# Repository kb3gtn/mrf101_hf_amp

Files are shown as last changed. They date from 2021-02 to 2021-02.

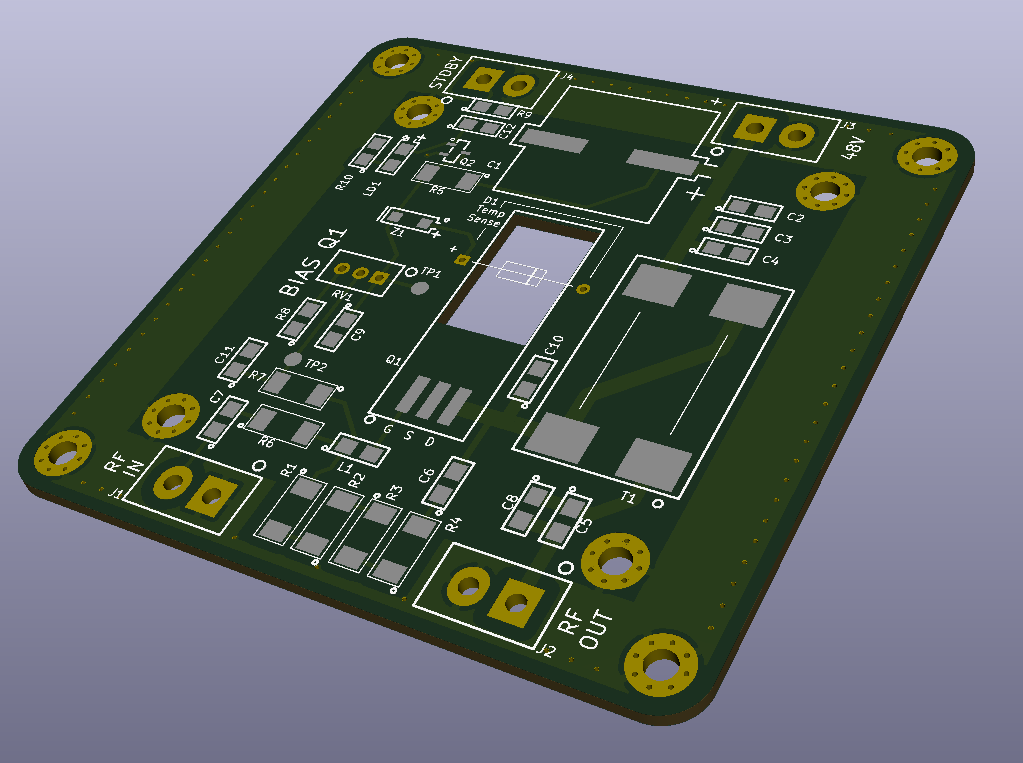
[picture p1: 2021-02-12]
Amp_Main_Deck/kicad/PCB_3D_Render.png

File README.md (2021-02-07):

# MRF101 HF AMP design

## Introduction
This repository contains multiple circuits board designs for a 100W HF Amp using a single MRF-101A transistor.   This design is based on a design by HF5L.   This design operates with a 48V Nominal supply at around 3.5 Amps of current.

Input match is good from 160M -> 6M band (1.8M -> 54 MHz).   Device has a between 16 -> 20 dB of gain depending on frequency.

## KICAD design files
The Main Amp Deck consists of the MRF101 transistor and input/output matching circuitry.
This can be found in the /Amp_Main_Deck/kicad folder in this repository.   The amplifier deck requires output filtering to remove odd harmonics produced by the Class AB amp.   The filters are selected per band of operation.

## Powering the Amp
The concept to power the amplifier design is to use 2 6S LiPo batteries in series.  This will provide a 44 -> 52v operating range.  Current plan is to use RC batteries and off the shelf chargers for portable operation.

## TODO
Design some BFP filters for each of the HF Amateur Radio bands, will need to develop a switch bank to select which filter should be in line.   Using BPF because this will provide some selectivity and limit the amount of bandwidth being sampled for a SDR receiver architecture.

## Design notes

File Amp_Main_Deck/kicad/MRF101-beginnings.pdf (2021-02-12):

## MRF-101 HF Amp 1.8-54 MHz

Peter Fetterer [ KB3GTN ]

Purpose of this project is to evaluate and generally dork around with some LDMOS MOSFET Amplifiers as a learning exercise. Looking around at possible devices I came across the MRF-101A transistor.

After a little googling I found a NXP Homebrew entry from Jim Veatch (WA2EUJ) where he made this device work as a broadband 100W Amp. So, to start of I decided to start with his design, build it, and see what it is capable of.

This is some documentation of some beginning test and evaluations of this Amplifier design.

The design files for this Amp are available on my Github located at the following URL: https://github.com/kb3gtn/mrf101_hf_amp

Schematic is available as a PDF in the repository.

3D render of the PCB created:


PCB dimensions:

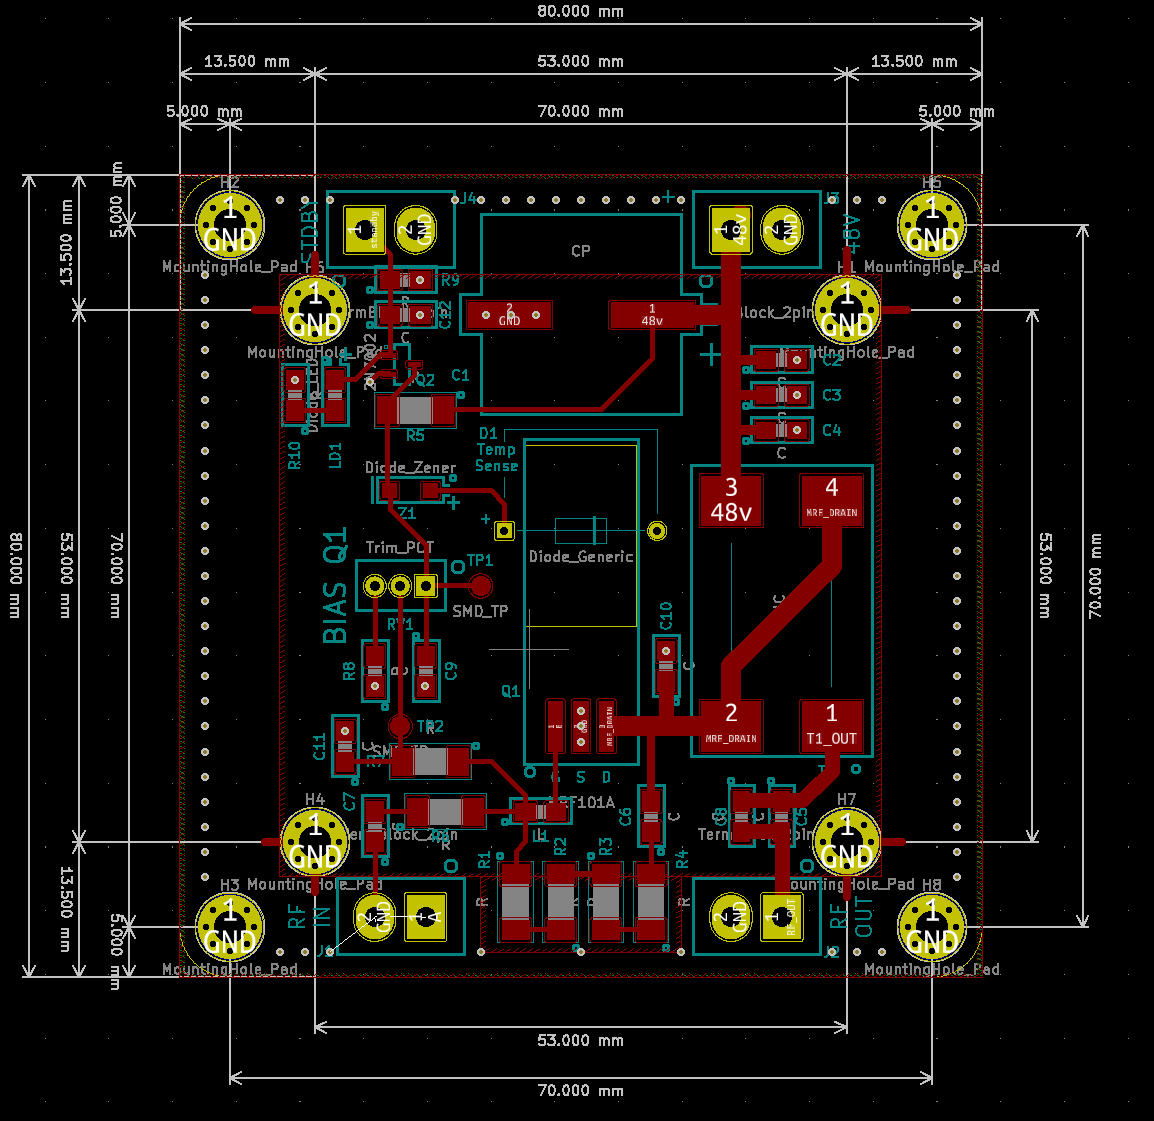
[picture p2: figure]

Heatsink mounts to inner hole pattern. Transistor mounts directly to heatsink.

The workbench for this project:

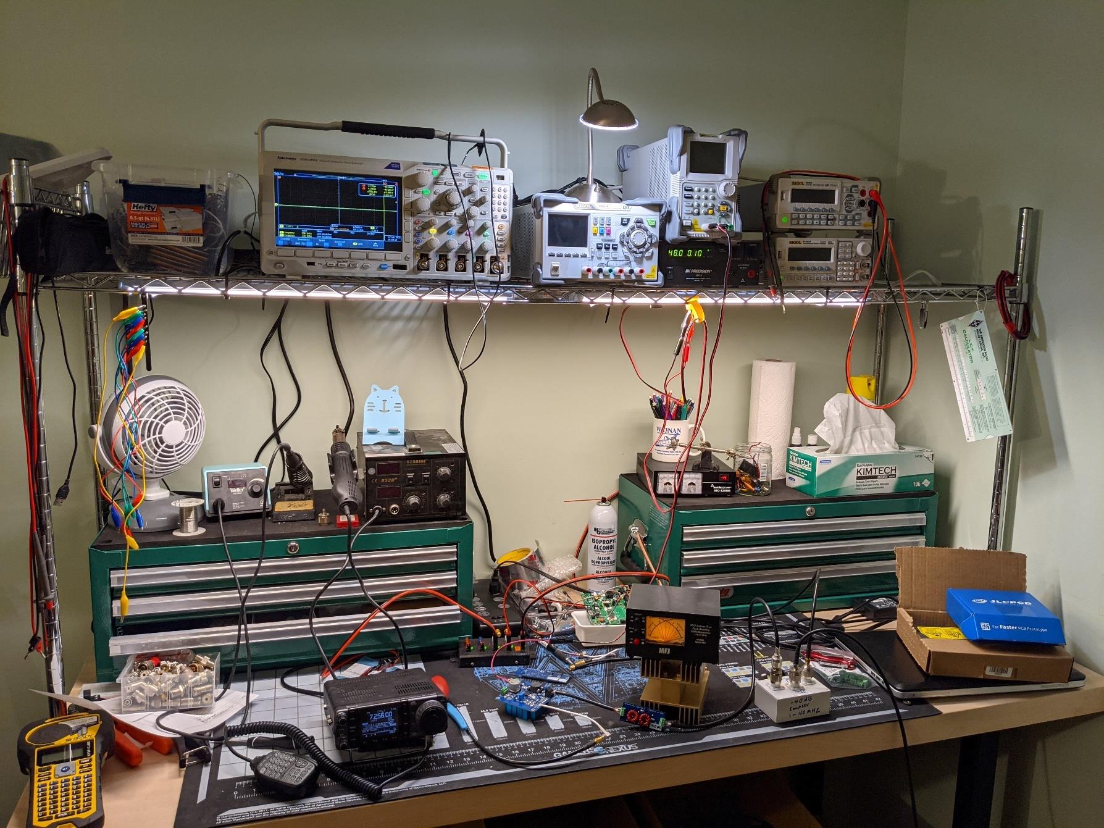
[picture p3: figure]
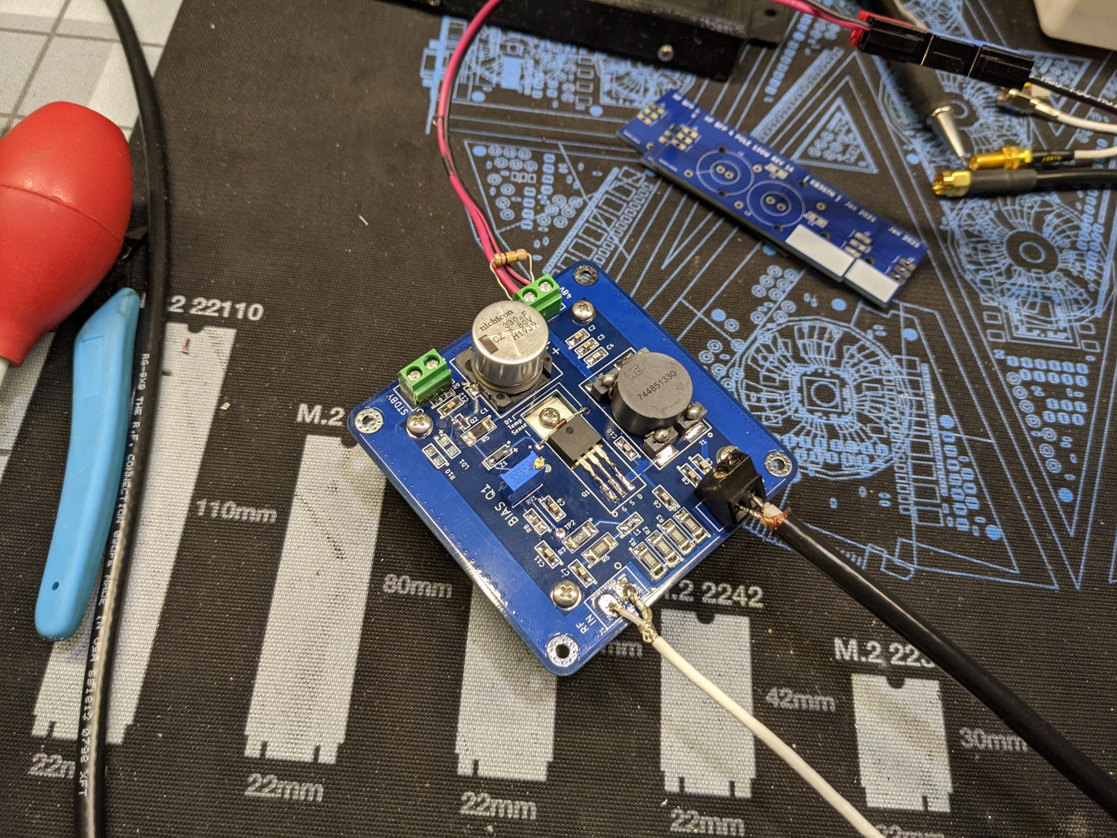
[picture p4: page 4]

HF Amplifier Deck close look.

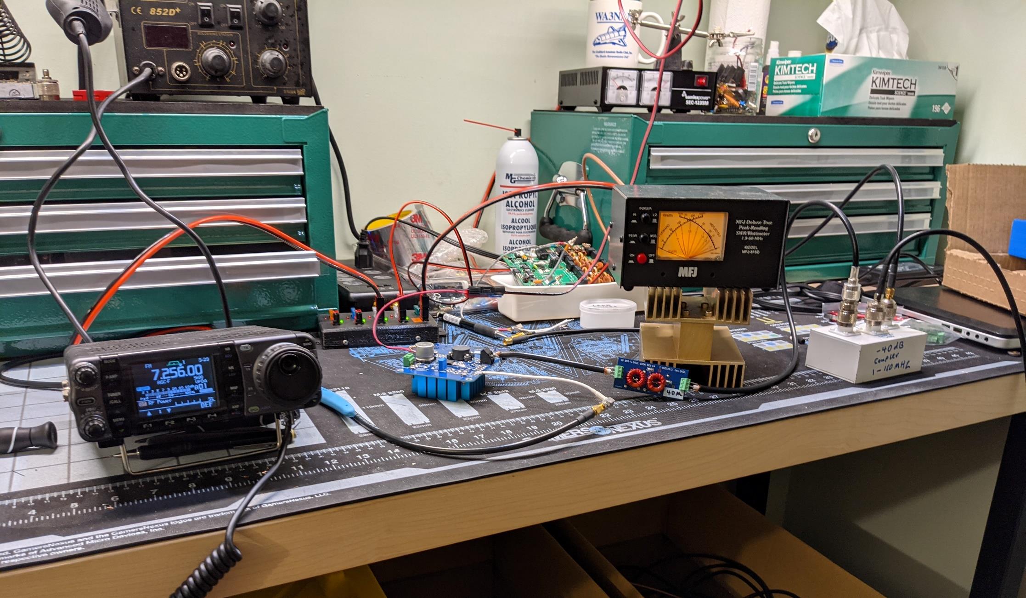
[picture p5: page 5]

Shows Amplifier Deck and Heatsink and a 40M BPF in test Configuration.

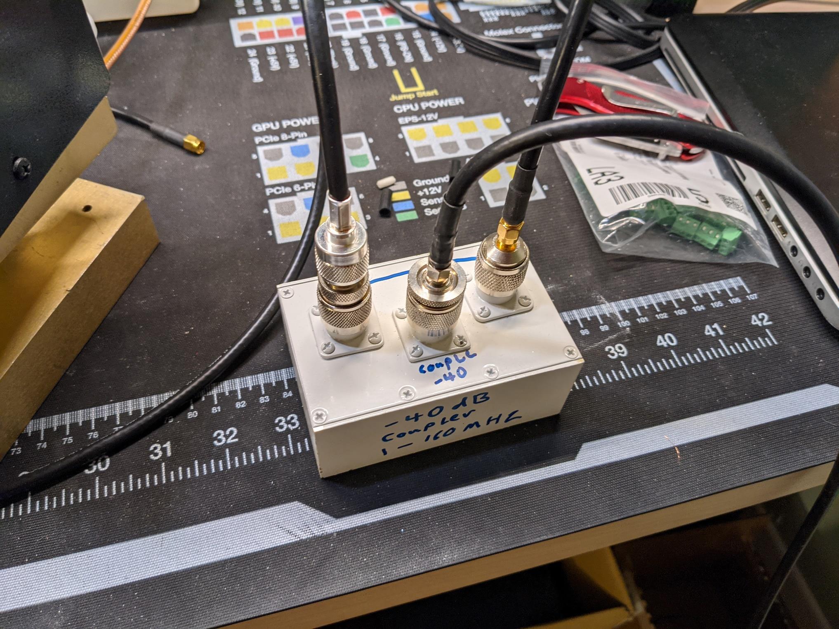
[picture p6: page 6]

Homebrew -40 dB coupler for looking at High Power signal on Spectrum Analyzer.

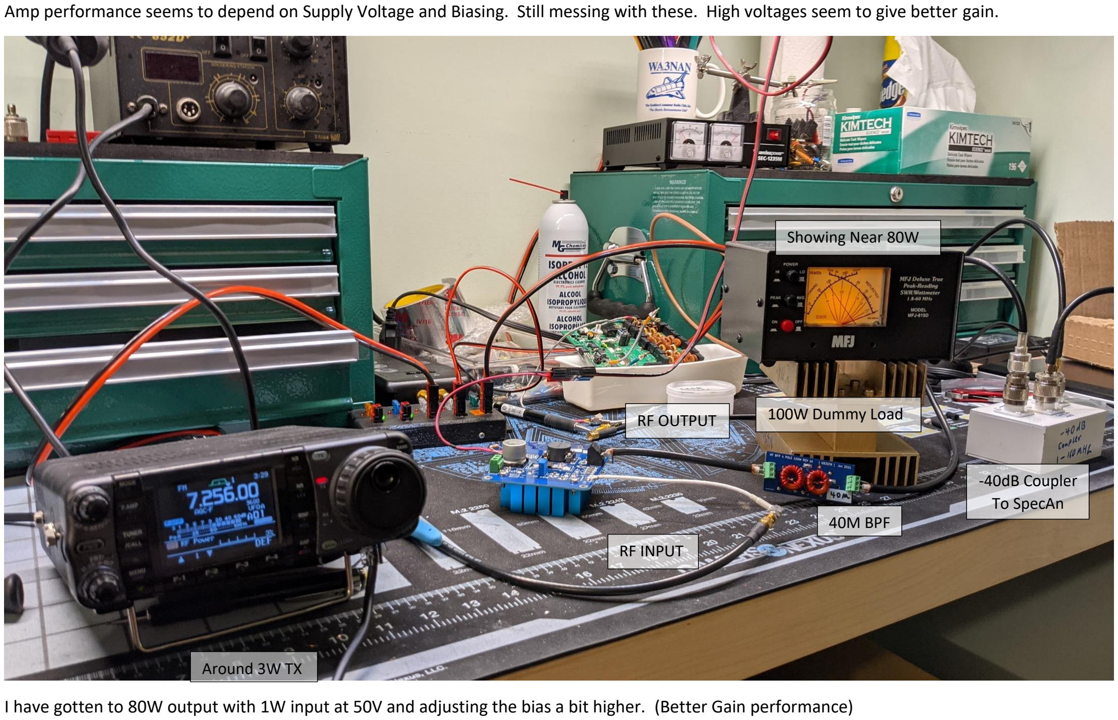
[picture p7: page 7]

Amp performance seems to depend on Supply Voltage and Biasing. Still messing with these. High voltages seem to give better gain.

I have gotten to 80W output with 1W input at 50V and adjusting the bias a bit higher. (Better Gain performance)

Around 3W TX

RF INPUT

RF OUTPUT

40M BPF

-40dB Coupler
To SpecAn

Showing Near 80W

100W Dummy Load

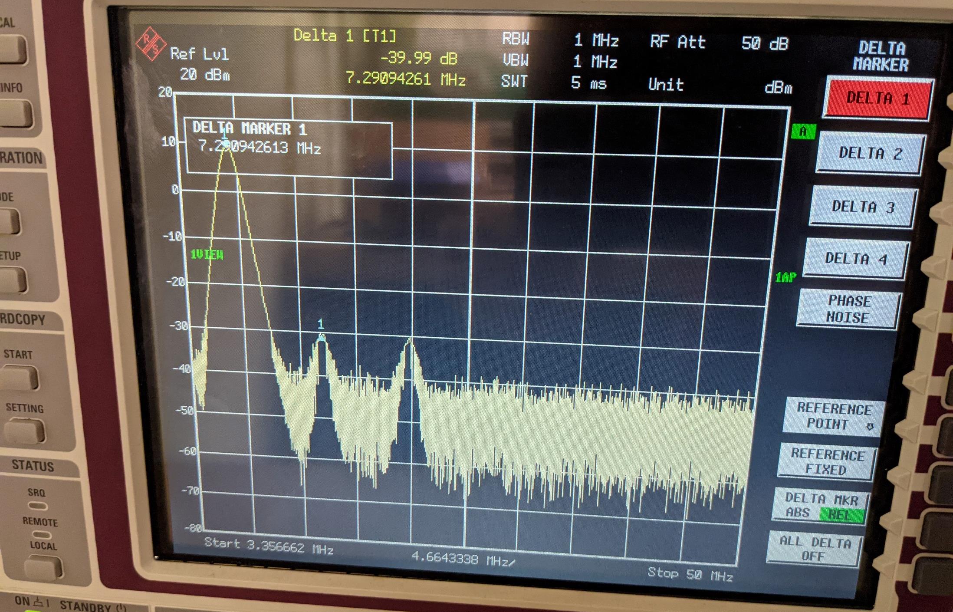
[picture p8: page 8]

Band Pass Filter Harmonic Suppression. Appears this configuration is providing about -40 dBc attenuation to 2nd and 3rd harmonics for 40M.

Conclusion:

Initial dorking around with the design seems to suggest it will do ok for project I want to use this for going forward. May rework this board to be Pre-Driver, MRF101 Amp, and Filter bank on a single board going for a small compact footprint that can run off an external 2 6S LiPo RC battery packs in series.

More to come, maybe..

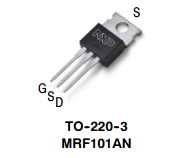
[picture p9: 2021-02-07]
Amp_Main_Deck/kicad/mrf101_pinout.png

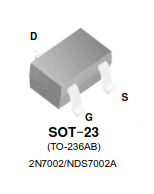
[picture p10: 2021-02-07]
Amp_Main_Deck/kicad/2n7002_pinout.png

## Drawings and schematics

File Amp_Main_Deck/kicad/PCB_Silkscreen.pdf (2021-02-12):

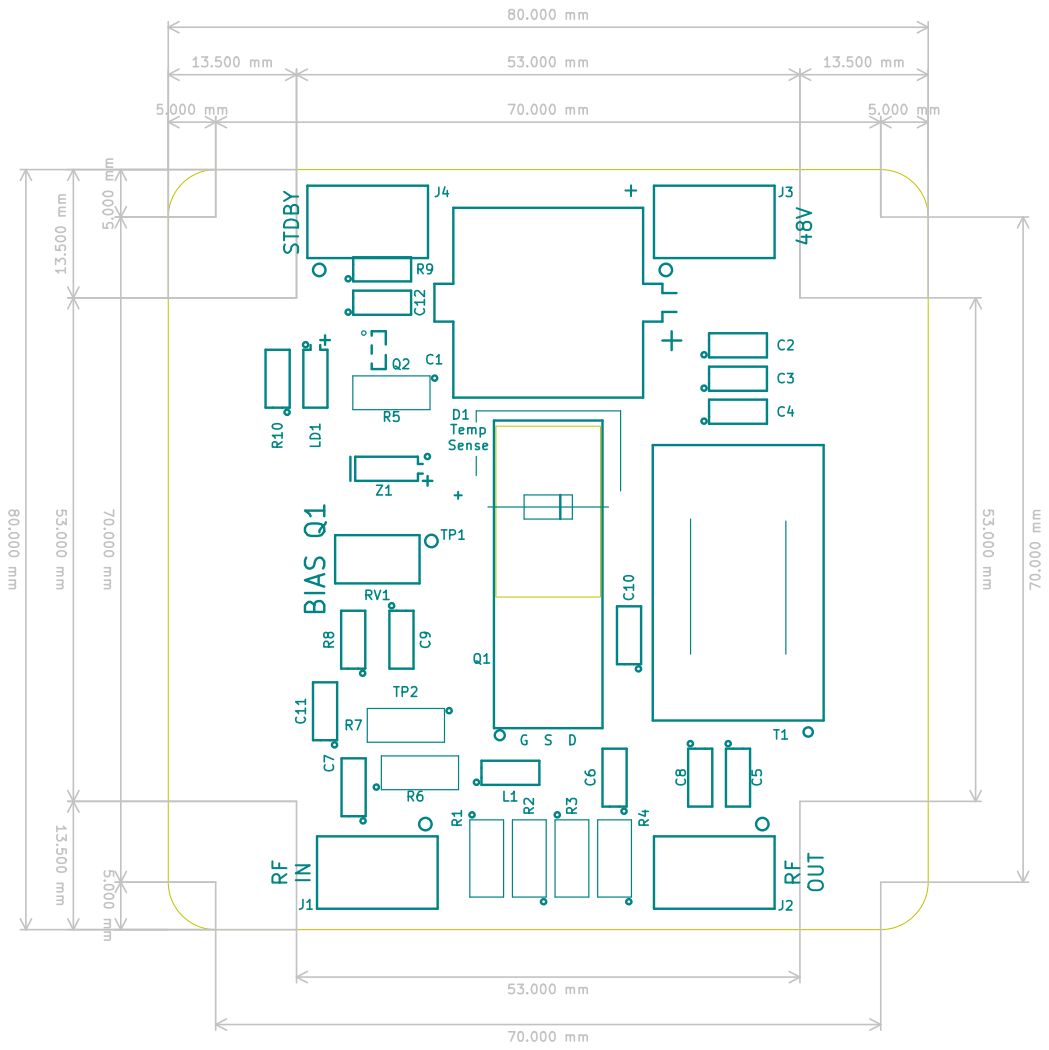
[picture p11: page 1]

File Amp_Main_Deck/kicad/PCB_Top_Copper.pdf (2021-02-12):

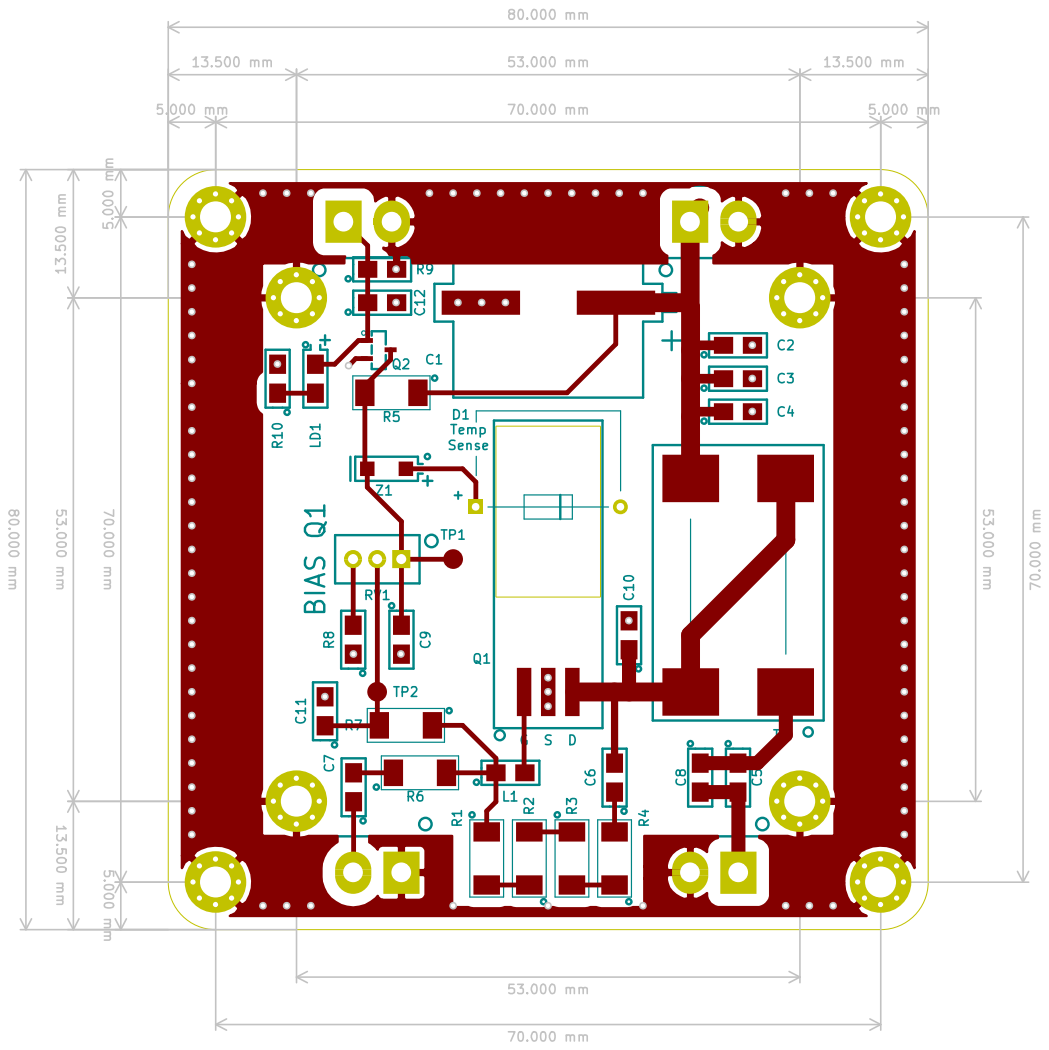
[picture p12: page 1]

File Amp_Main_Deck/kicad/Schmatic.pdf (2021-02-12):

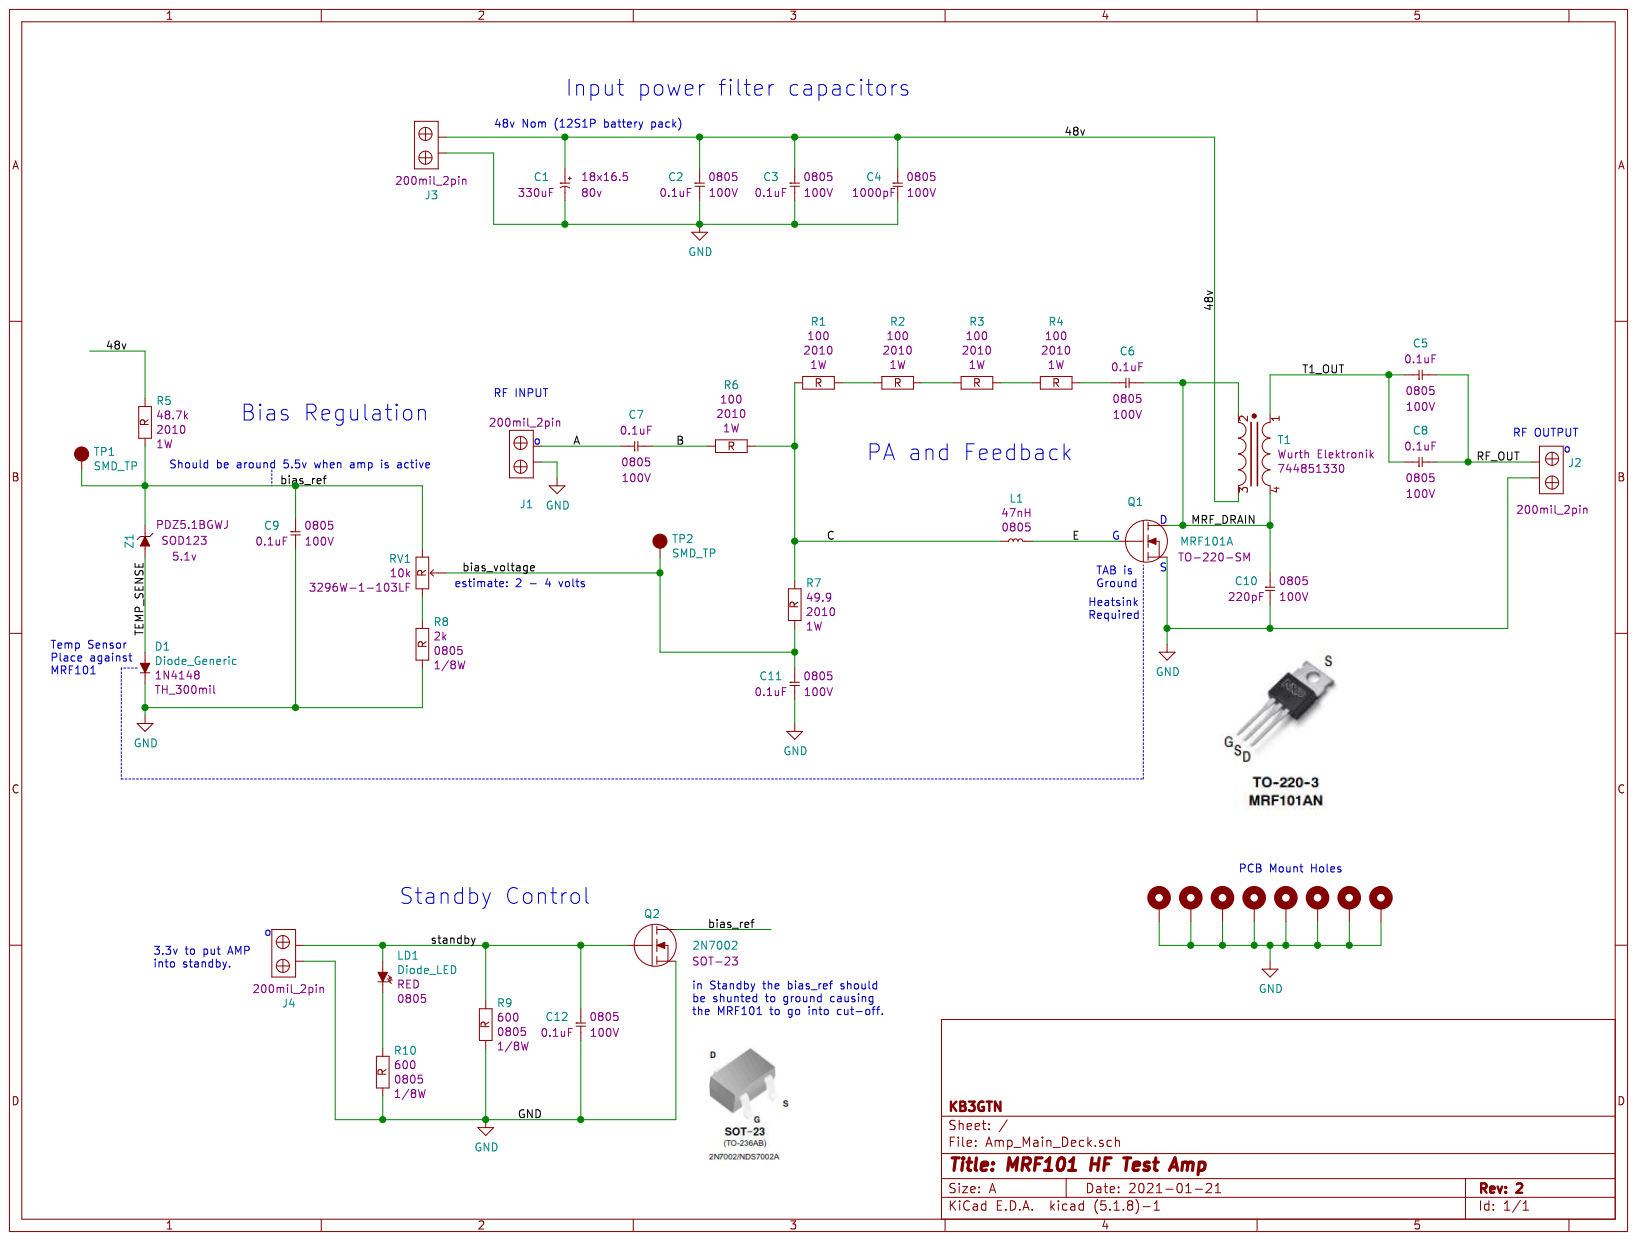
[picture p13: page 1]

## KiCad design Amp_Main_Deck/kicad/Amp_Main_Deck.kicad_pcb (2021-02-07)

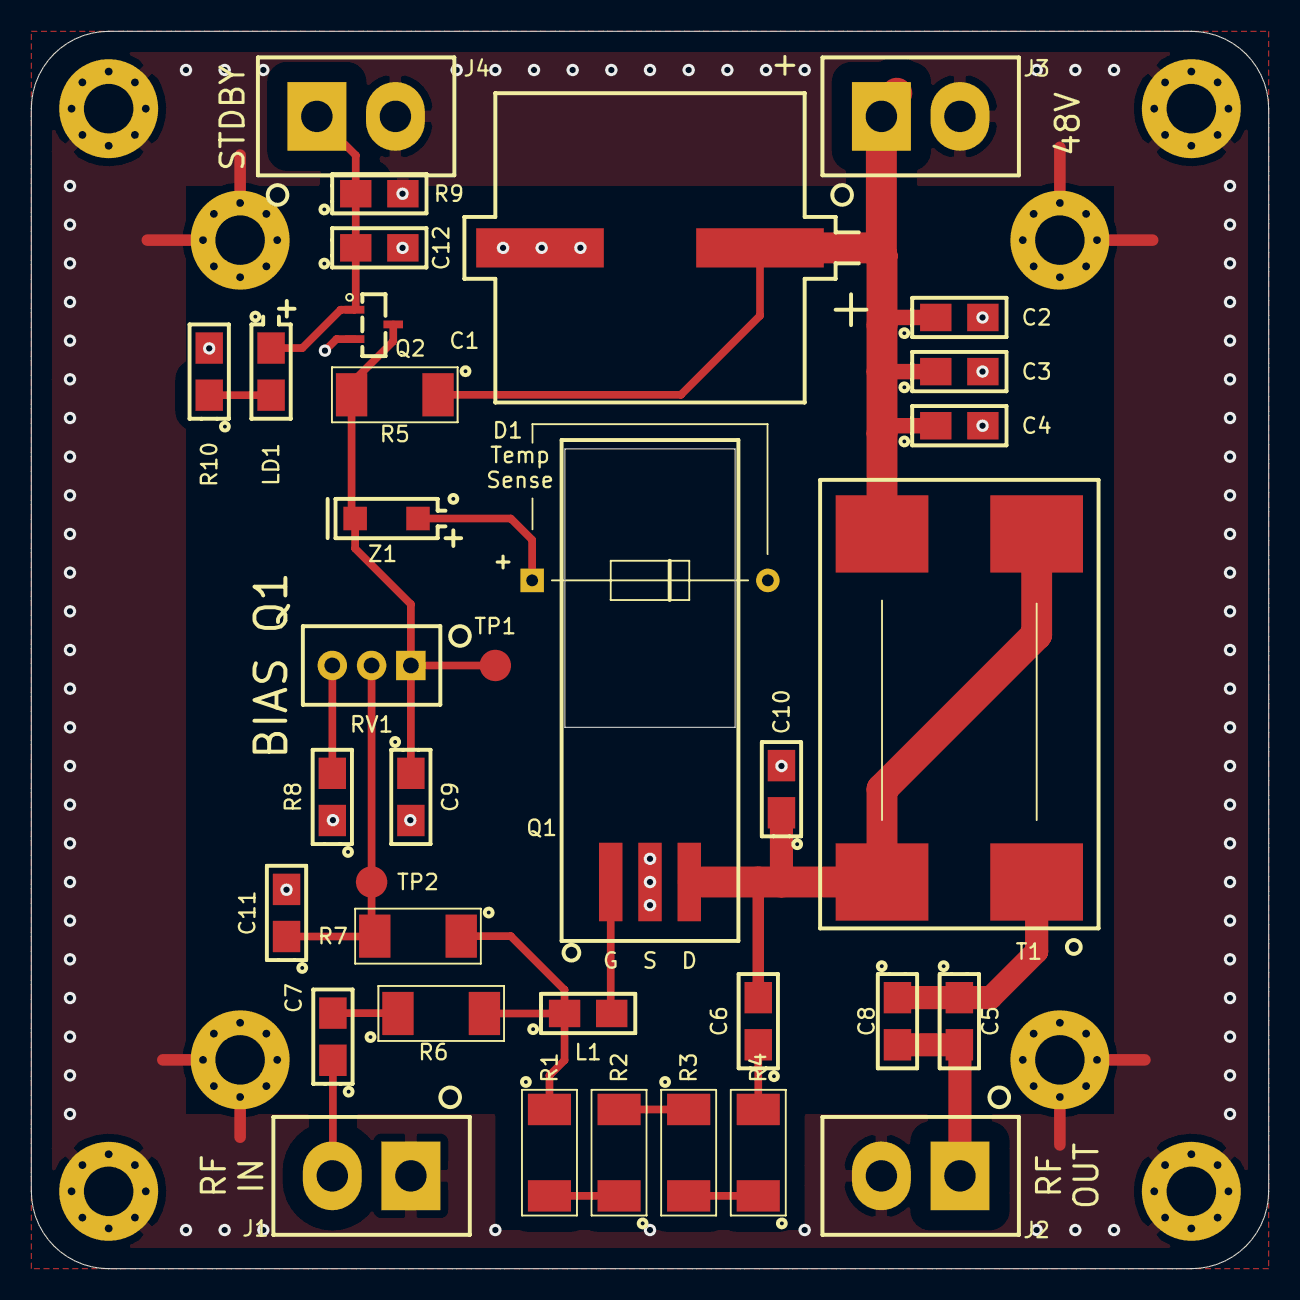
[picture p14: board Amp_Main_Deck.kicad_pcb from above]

Board: 2 copper layers, 80.0 x 80.0 mm, 44 parts (0 on the bottom side), 19 nets.

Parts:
C1: CP; UCZ1K331MNQ1MS
C2, C3, C4, C5, C6, C7, C8, C9, C10, C11, C12: C; 0805_handsolder
D1: Diode_Generic; Diode_600mil
H1, H2, H3, H4, H5, H6, H7, H8: MountingHole_Pad; MountingHole_3.2mm_M3_Pad_Via
J1, J2, J3, J4: TermBlock_2pin; TermBlock_200mil_2pin
L1: L; 0805_handsolder
LD1: Diode_LED; 0805_handsolder_Pol
Q1: MRF101A; MRF-101AN_SM
Q2: 2N7002; SOT-23
R1, R2, R3, R4, R5, R6, R7: R; 2010_handsolder
R8, R9, R10: R; 0805_handsolder
RV1: Trim_POT; 3296W-1-103LF
T1: CMC; 744851330
TP1, TP2: SMD_TP
Z1: Diode_Zener; SOD123

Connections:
/48v: C1.1, C2.1, C3.1, C4.1, J3.1, R5.1, T1.3
/A: C7.1, J1.1
/B: C7.2, R6.1
/C: L1.1, R1.1, R6.2, R7.1
/E: L1.2, Q1.1
/MRF_DRAIN: C6.2, C10.1, Q1.3, T1.2, T1.4
/RF_OUT: C5.2, C8.2, J2.1
/T1_OUT: C5.1, C8.1, T1.1
/TEMP_SENSE: D1.1, Z1.1
/bias_ref: C9.1, Q2.2, R5.2, RV1.1, TP1.1, Z1.2
/bias_voltage: C11.1, R7.2, RV1.2, TP2.1
/standby: C12.1, J4.1, LD1.1, Q2.1, R9.1
GND: C1.2, C2.2, C3.2, C4.2, C9.2, C10.2, C11.2, C12.2, D1.2, H1.1, H2.1, H3.1, H4.1, H5.1, H6.1, H7.1, H8.1, J1.2, J2.2, J3.2, J4.2, Q1.2, Q2.3, R8.1, R9.2, R10.2
unnamed: C6.1, R4.2
unnamed: LD1.2, R10.1
unnamed: R1.2, R2.1
unnamed: R2.2, R3.1
unnamed: R3.2, R4.1
unnamed: R8.2, RV1.3
